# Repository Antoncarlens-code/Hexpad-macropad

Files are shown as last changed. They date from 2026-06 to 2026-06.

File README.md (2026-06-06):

# Hexpad — a hex-shaped 6-key macropad

A 6-key (3×2) macropad with a rotary encoder: 3D-printed case, custom 2-layer PCB,
and KMK firmware, driven by a **Seeed XIAO RP2040**. Keys wire **direct to GPIO**
(no matrix, no diodes), and the encoder handles volume/scroll.

<!-- HACKPAD: a full render showing ALL parts is required. Export one from the
     KiCad 3D viewer or your CAD tool and drop it at the path below. -->
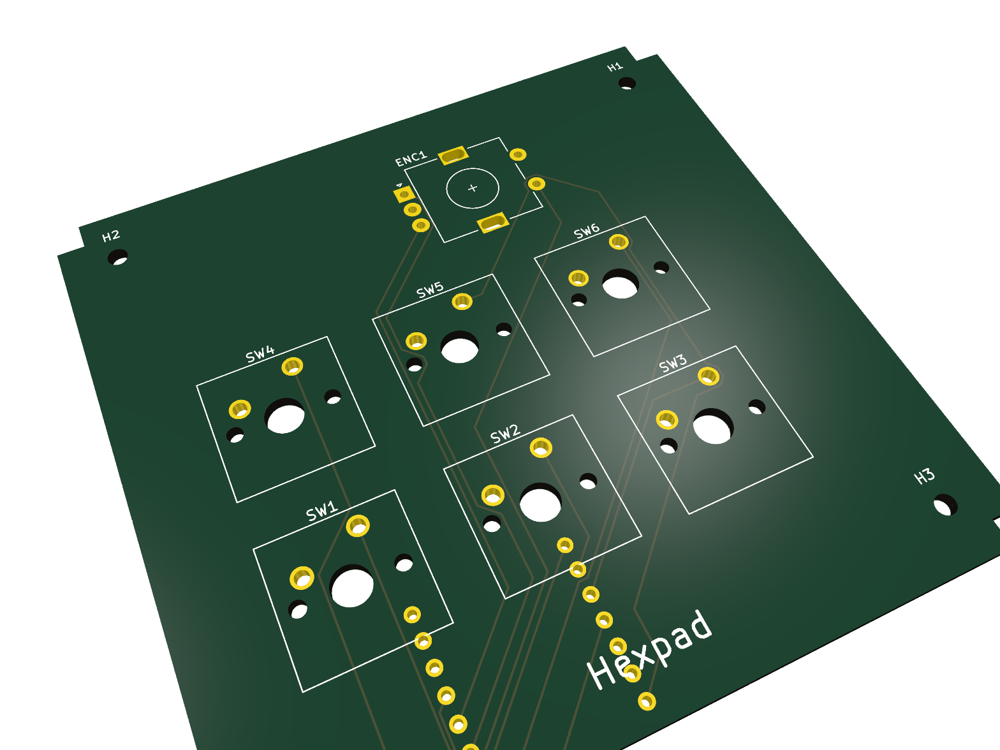
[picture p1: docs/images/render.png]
Hexpad full render


## Inspiration & challenges

I wanted a compact editing/clipboard pad with a volume knob that didn't look like
every other square macropad — so Hexpad uses a hexagonal silhouette around a
centered 3×2 key cluster with the encoder up top.

Two things were genuinely fiddly. First, the original top-plate CAD came out of an
early IDE session malformed — the plate solid was fused to a stray slab 74 mm
below it, so it "levitated" in the slicer. I had to reverse-engineer the real
dimensions from the STEP geometry and rebuild the plate as a clean parametric
build123d script. Second, rather than hand-draw the board I generated the PCB
programmatically with KiCad's `pcbnew` API from a single coordinate spec, which
guarantees the switch, encoder, and mounting-hole positions line up exactly with
the printed plate (19.05 mm pitch, mounts at ±32 × ±31 mm).

## Gallery

| Schematic | PCB | Case |
|---|-----|---|
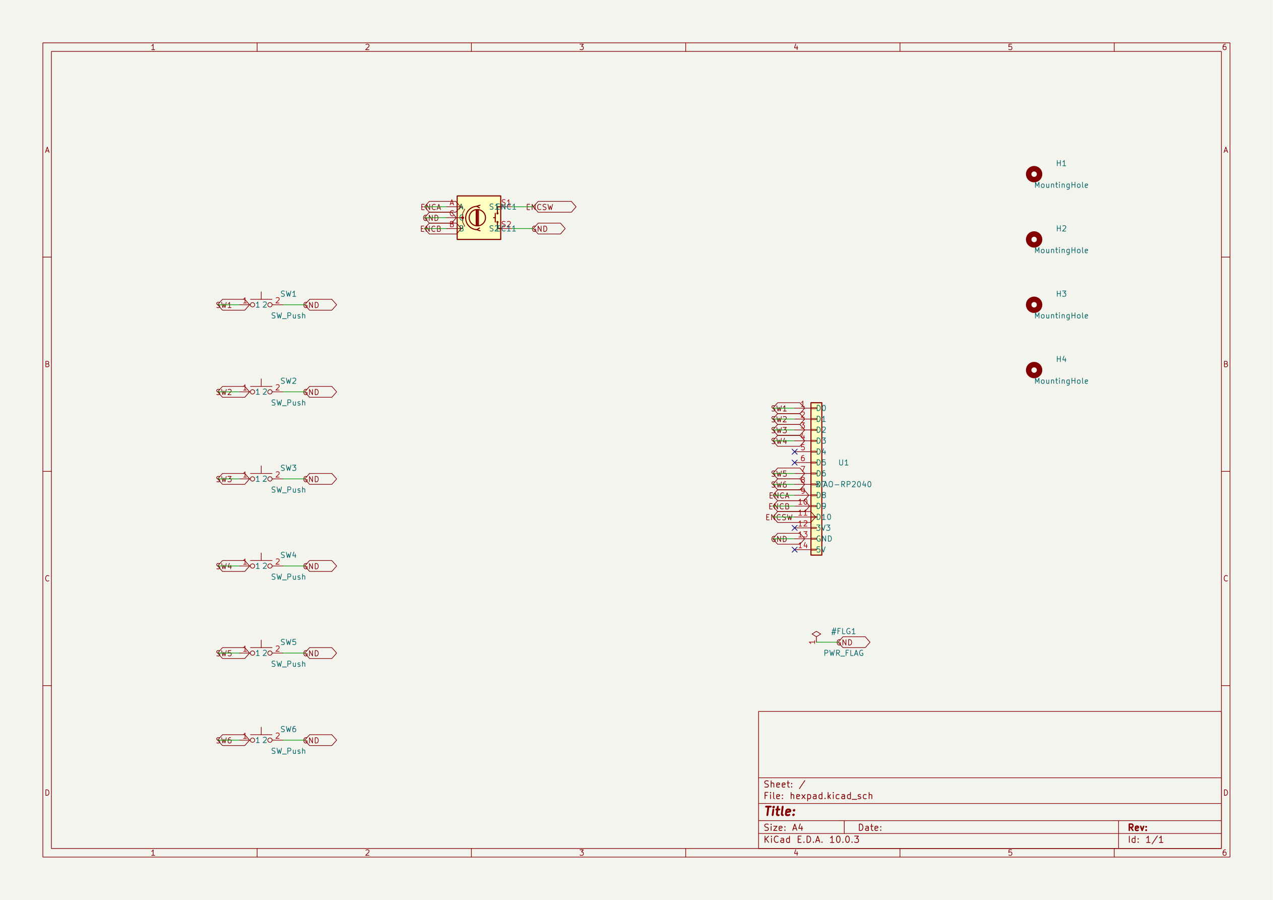
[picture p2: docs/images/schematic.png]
Schematic
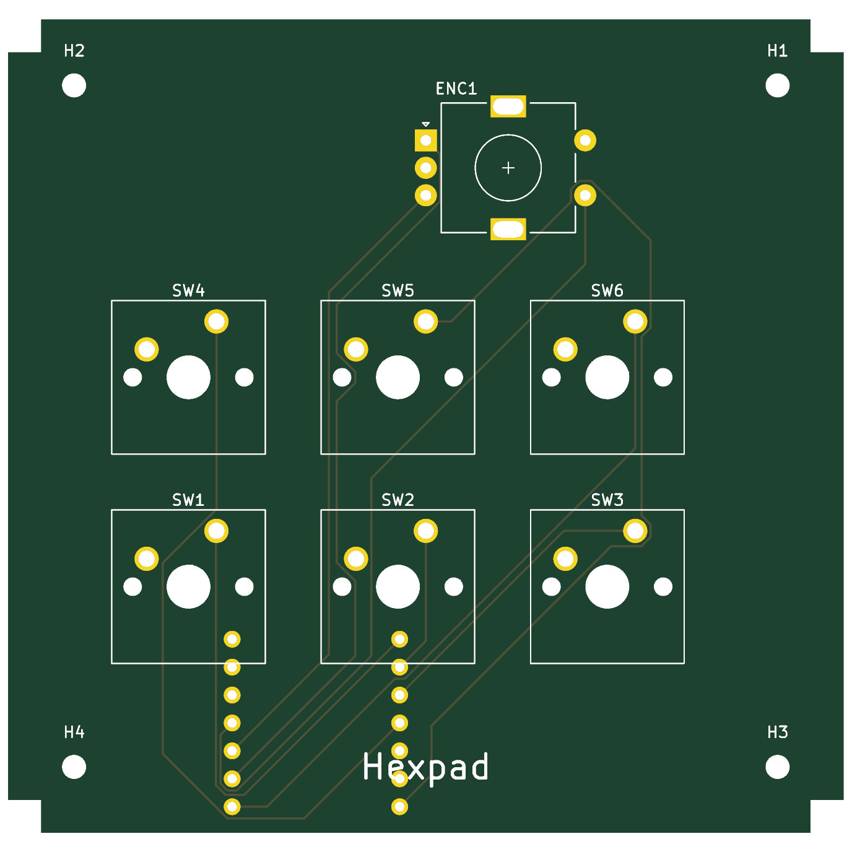
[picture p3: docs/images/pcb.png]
PCB
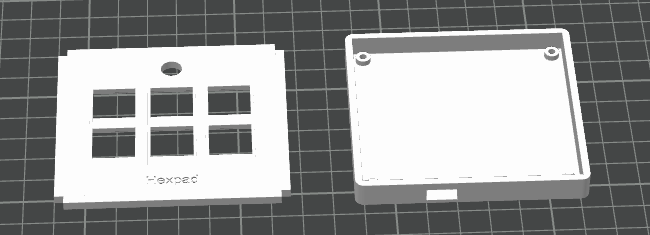
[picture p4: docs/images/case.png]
Case
|  |  |  |

<!-- HACKPAD requires a photo of each: the schematic, the PCB (KiCad render or the
     real board), and the case. Add the three images to docs/images/. -->

## Bill of materials

Full sheet: [`docs/electronics/hexpad-bom.csv`](docs/electronics/hexpad-bom.csv).

| Qty | Part | Notes |
|-----|---|---|
| 1 | Seeed XIAO RP2040 | MCU, mounted on the back; USB-C exits the front edge |
| 6 | Cherry MX (or compatible) switch | `MX_Only_1.00u`, direct-wired, one GPIO each |
| 1 | Alps EC11 rotary encoder w/ switch | A/B + push → 3 GPIO, common → GND |
| 4 | M2 screw (~6 mm) | through the case into the plate's corner posts |
| 6 / 1 | MX keycaps / encoder knob | cosmetic |
| 0 | diodes | **none** — direct wiring is valid for ≤7 keys |

## Project layout

| Folder | Contents |
|---|---|
| `cad/` | Enclosure: STEP blueprints + parametric build123d source |
| `pcb/` | KiCad 10 PCB project, schematic, + fabrication Gerbers |
| `firmware/` | KMK (CircuitPython) keymap |
| `docs/electronics/` | Schematic (SVG), BOM, PCB design notes |
| `docs/images/` | Render + schematic/PCB/case photos for this README |

## PCB

| File | Purpose |
|---|---|
| `pcb/hexpad.kicad_sch` | Schematic (XIAO + 6 switches + encoder) |
| `pcb/hexpad.kicad_pcb` | KiCad 10 board, branded, routed |
| `pcb/hexpad-gerbers.zip` | **Upload to JLCPCB** to order boards |
| `pcb/build_hexpad_pcb.py` / `build_hexpad_sch.py` | Regenerate board/schematic from the spec |

2-layer, **76 × 74 mm** (within the 100 mm limit), silkscreen-branded "Hexpad",
matching the plate's switch / encoder / mounting coordinates.

## Firmware

KMK keymap at `firmware/code.py`. Default: front row Copy/Paste/Cut, rear row
Undo/Redo/Save, encoder = volume (press = mute). See `firmware/README.md` for
flashing and remapping.

## Pin map

| Input | XIAO pin | | Input | XIAO pin |
|---|---|-|---|---|
| SW1–SW3 (front) | D0, D1, D2 | | Encoder A / B | D8 / D9 |
| SW4–SW6 (rear) | D3, D6, D7 | | Encoder push | D10 |

`D4`/`D5` (SDA/SCL) left free for a future OLED. All inputs use the RP2040's
internal pull-ups.

## Toolchain

build123d (CAD → STEP) · KiCad 10 (PCB) · Bambu Studio (slicing) · CircuitPython + KMK.

## Submission checklist (Hackpad)

- [x] DRC: 0 errors, 0 unconnected (only silk + courtyard warnings) — re-plotted after branding
- [x] "Hexpad" on the PCB silkscreen
- [x] "Hexpad" engraved on the top plate (front margin, 0.6 mm deep) — **reprint the plate to get it physically**
- [ ] 3D-printed parts need no supports / tolerances ~0.25 mm *(verify on your physical print)*
- [x] PCB < 100 × 100 mm; ≤16 switches, ≤2 encoders, ≤1 OLED, ≤16 LEDs
- [x] README photos: render + PCB + schematic + case (`docs/images/`)

## Build checklist

- [x] CAD: top plate + bottom case
- [x] PCB: schematic + routed board + Gerbers
- [x] Firmware keymap
- [x] Re-plot Gerbers after the silkscreen branding change
- [ ] Order PCB from JLCPCB · print case · solder · flash · assemble

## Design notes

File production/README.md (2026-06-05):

# Production files

Manufacturing-ready outputs for Hexpad (separate from the source/design files).

| File | What it is |
|---|---|
| `gerbers.zip` | PCB fabrication Gerbers + drill files (2-layer, 76 × 74 mm). Upload to a fab house (e.g. JLCPCB) to make the board. |
| `hexpad_top_plate.step` | Top plate — print this part. |
| `hexpad_bottom_case.step` | Bottom case — print this part. |
| `main.py` | KMK firmware. Copy onto the XIAO's CIRCUITPY drive alongside the `kmk/` library (see `../firmware/README.md`). |

Source/design files live in `../cad`, `../pcb`, and `../firmware`.

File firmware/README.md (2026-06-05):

# Firmware

KMK (CircuitPython) firmware for the hexpad macropad — 6 keys + 1 rotary encoder
on a **Seeed XIAO RP2040**. KMK is used because it needs no build toolchain:
you drag files onto the board's USB drive and edit `code.py` to remap keys.

## Files

| File | Purpose |
|---|---|
| `code.py` | The keymap + wiring. This is the firmware you edit. |

## Flash it (one-time setup)

1. **Put CircuitPython on the XIAO RP2040.**
   - Download the XIAO RP2040 build: <https://circuitpython.org/board/seeeduino_xiao_rp2040/>
   - Plug the XIAO in. Enter the bootloader: hold **BOOT**, tap **RESET**, release BOOT
     (or double-tap RESET). A drive named **RPI-RP2** appears.
   - Drag the downloaded `.uf2` onto **RPI-RP2**. It reboots as a drive named **CIRCUITPY**.
2. **Add the KMK library.**
   - Download KMK: <https://github.com/KMKfw/kmk_firmware> (green *Code → Download ZIP*).
   - Copy the **`kmk/`** folder from that zip to the root of the **CIRCUITPY** drive.
3. **Add this firmware.**
   - Copy **`firmware/code.py`** to the root of **CIRCUITPY** (replace the default `code.py`).
   - It runs immediately. Press a key / turn the knob to test.

To change keys later: just edit `code.py` on the CIRCUITPY drive and save — it
reloads automatically.

## Default keymap

```
   ( encoder: turn = volume,  press = mute )

   [ Copy ] [ Paste ] [ Cut  ]      <- front row  (SW1 SW2 SW3)
   [ Undo ] [ Redo  ] [ Save ]      <- rear row   (SW4 SW5 SW6)
```

Edit the `KC.*` entries in `code.py` to remap. Examples are in the comments
there (plain keys, Ctrl/Cmd combos, media keys).

## Pin map (matches the PCB)

Each switch: pin → GND, internal pull-up (press = LOW). No diodes.

| Key | XIAO pin | RP2040 GPIO |
|-----|---|---|
| SW1 | D0 | GPIO26 |
| SW2 | D1 | GPIO27 |
| SW3 | D2 | GPIO28 |
| SW4 | D3 | GPIO29 |
| SW5 | D6 | GPIO0 |
| SW6 | D7 | GPIO1 |
| Encoder A | D8 | GPIO2 |
| Encoder B | D9 | GPIO4 |
| Encoder push | D10 | GPIO3 |
| Encoder common / switch GND | GND | — |

`code.py` uses the `board.D#` names, so it stays correct regardless of the
underlying GPIO numbers.

## Troubleshooting (first power-on)

You can test the firmware **before** assembling the case — just flash a bare XIAO
and briefly bridge a switch pin to a GND pin with a jumper to confirm a key fires.

- **No `RPI-RP2` drive when entering the bootloader.** Use a *data* USB-C cable
  (charge-only cables won't enumerate). Re-do the bootloader: hold **BOOT**, tap
  **RESET**, release BOOT.
- **`CIRCUITPY` never appears after copying the `.uf2`.** The `.uf2` didn't take —
  re-enter the bootloader and drag it on again. Make sure you grabbed the
  *XIAO RP2040* build, not a different board.
- **Nothing happens after copying `code.py`.** There's an error. Open
  `boot_out.txt` on the CIRCUITPY drive, or connect a serial console
  (Mu editor, or `screen`/PuTTY) to see the traceback. The usual culprits:
  - **`ImportError: cannot import name 'KeysScanner'`** — the import path moved
    between KMK versions. Change the import in `code.py` to:
    `from kmk.scanners import keypad` and then use `keypad.KeysScanner(...)`.
  - **`kmk` not found** — the `kmk/` library folder isn't at the root of
    CIRCUITPY (it must be `CIRCUITPY/kmk/...`, not nested in another folder).
- **A single key does nothing** (others work) — almost always a cold solder joint
  on that switch or its pin; reflow it. To rule out the firmware, bridge that
  XIAO pin to GND by hand; if it fires, it's the joint, not the code.
- **All keys dead, encoder works (or vice-versa)** — re-check that pin list vs.
  the [pin map](#pin-map-matches-the-pcb) above.
- **Encoder turns the "wrong" way** (volume down when you expect up) — swap the
  first two entries in `encoder.map`, i.e. `(KC.VOLU, KC.VOLD, KC.MUTE)`. (Swapping
  the A/B wires does the same thing in hardware.)
- **Keys repeat / feel chattery** — add light debounce: `keyboard.debug_enabled`
  off and, if needed, raise the scanner's debounce; usually not necessary on MX.

## Prefer QMK?

QMK also runs on the RP2040 but needs a compile toolchain (`qmk` CLI, a
`info.json` declaring `direct` pins for the 6 keys + an `encoders` block, and a
`keymap.c`). KMK is recommended here for the no-build workflow; ask if you want
the QMK variant instead.

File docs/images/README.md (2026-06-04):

# README images

Drop the images the top-level README references here (Hackpad requires all four):

- `render.png` — a full render showing **all** parts (KiCad 3D viewer or CAD).
- `schematic.png` — screenshot of the KiCad schematic.
- `pcb.png` — KiCad PCB render or a photo of the real board.
- `case.png` — photo of the printed case.

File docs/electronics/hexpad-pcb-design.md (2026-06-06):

# Hexpad PCB Design Package

**Date:** 2026-06-03
**Scope:** Electrical design for the existing 6-key + encoder hexpad enclosure.
**Matches:** `cad/hexpad_top_plate.py` (constants), `cad/hexpad_assembly.step`.

This is the design half the project was missing — everything needed to build the
KiCad schematic and PCB so it drops into the printed case. All coordinates are
taken directly from the CAD source so the board lines up with the plate's switch
cutouts, encoder hole, and corner posts.

---

## 1. What this board is

A **6-key** macropad (3×2 grid) plus **one EC11 rotary encoder**, driven by a
**Seeed XIAO RP2040**. Because there are fewer than 8 keys, every switch wires
**directly to its own GPIO** — no matrix, **no diodes**. The tutorial's matrix /
`1N4148` section does not apply to this build and should be skipped.

Pin budget: 6 switches + 3 encoder = **9 GPIO**. The XIAO RP2040 exposes 11
(D0–D10), so it fits with two pins (D4/D5 = SDA/SCL) left free for a future OLED.

---

## 2. Bill of materials

See `hexpad-bom.csv` for the spreadsheet version. Summary:

| Ref | Qty | Part | Footprint |
|-----|-----|---|---|
| U1 | 1 | Seeed XIAO RP2040 | care-package XIAO (castellated) |
| SW1–SW6 | 6 | MX keyswitch 1u | `MX_Only_1.00u` (care package) |
| ENC1 | 1 | Alps EC11 encoder + switch | `RotaryEncoder_Alps_EC11E-Switch_Vertical_H20mm` |
| — | 4 | M2 screw (~6 mm) | into plate corner posts |
| — | 6 / 1 | keycaps / encoder knob | cosmetic |

Diodes: **none.** (Listed in the BOM as qty 0 for reference only.)

---

## 3. Pin map / wiring table

Switch numbering: row by row, **front row first** (front = −Y), left to right.

| Ref | Function | XIAO pin | RP2040 GPIO | Other leg |
|-----|---|---|---|---|
| SW1 | key, front-left | D0 | GPIO26 | GND |
| SW2 | key, front-center | D1 | GPIO27 | GND |
| SW3 | key, front-right | D2 | GPIO28 | GND |
| SW4 | key, rear-left | D3 | GPIO29 | GND |
| SW5 | key, rear-center | D6 | GPIO0 | GND |
| SW6 | key, rear-right | D7 | GPIO1 | GND |
| ENC1.A | encoder rotation A | D8 | GPIO2 | — |
| ENC1.B | encoder rotation B | D9 | GPIO4 | — |
| ENC1.SW | encoder push | D10 | GPIO3 | — |
| ENC1.C | encoder common | — | — | GND |
| *(reserved)* | OLED SDA | D4 | GPIO6 | future |
| *(reserved)* | OLED SCL | D5 | GPIO7 | future |

Every input uses the RP2040's **internal pull-up** (firmware: `INPUT_PULLUP`),
so a press/turn pulls the pin to GND. No external resistors. See
`hexpad-schematic.svg` for the wiring diagram.

---

## 4. PCB layout coordinates

Origin = plate center (same origin as the CAD). Units mm. **Front edge = −Y**
(the case USB-C slot is cut into the −Y wall at X −15…−5).

### Switches (center of each MX footprint) — 19.05 mm pitch

| Ref | X | Y |
|-----|---|---|
| SW1 | −19.05 | −9.525 |
| SW2 | 0.00 | −9.525 |
| SW3 | +19.05 | −9.525 |
| SW4 | −19.05 | +9.525 |
| SW5 | 0.00 | +9.525 |
| SW6 | +19.05 | +9.525 |

### Encoder

| Ref | X | Y |
|-----|---|---|
| ENC1 | 0.00 | +26.00 |

### Mounting holes (M2, must clear the plate's corner posts)

| Hole | X | Y |
|---|---|---|
| H1 | +32.00 | +31.00 |
| H2 | −32.00 | +31.00 |
| H3 | +32.00 | −31.00 |
| H4 | −32.00 | −31.00 |

X = ±32 (not ±31) to line up with the bottom-case screw bosses, which sit at
X ±32, Y ±31.

Drill Ø2.2 mm (M2 clearance), ~4 mm pad/annular keep-out.

### XIAO (U1)

Place on the **back** layer, USB-C connector pointing −Y, USB centered near
**X ≈ −10** so it lines up with the case slot. Body roughly centered at
**(−10, −27)** in the front margin below the bottom key row (which ends near
Y ≈ −16.5). Flip to B.Cu (press F in KiCad) before routing.

### Board outline (Edge.Cuts)

Match the plate footprint: **76 × 74 mm** rectangle (X ±38, Y ±37) with a
**3 × 3 mm notch at each corner**. Inset the edge **0.5 mm** all around if you
want clearance inside the case rim. Well within the 100 × 100 mm limit.

---

## 5. Build order in KiCad (condensed, tailored to this design)

1. New project → Schematic Editor. Place `MOUDLE-SEEEDUINO-XIAO`, 6× `SW_Push`,
   1× `RotaryEncoder_Switch`. **No diodes.**
2. Wire per the table in §3; place `GND` symbols on every switch's second leg and
   the encoder common.
3. Assign footprints per §2. (XIAO + `MX_Only_1.00u` come from the care package.)
4. PCB Editor → Update PCB from Schematic. Flip U1 to back.
5. Place SW1–SW6, ENC1, and the 4 mounting holes at the §4 coordinates (set grid
   to 19.05 mm for the switches).
6. Route on F.Cu; use B.Cu + a via only where traces cross.
7. Draw the §4 board outline on Edge.Cuts.
8. Cleanup Tracks & Vias → DRC (expect 0 errors) → 3D viewer check.
9. Fabrication Outputs → Gerbers + Drill files → zip as `gerbers.zip` → upload to
   JLCPCB for the preview/quote.

---

## 6. Integration checklist (board ↔ enclosure)

- [ ] Switch centers match plate cutouts (the 6 coords above = CAD `KEY_LOCS`). ✓ by design
- [ ] Encoder at (0, +26) = CAD `ENCODER_POS`. ✓ by design
- [ ] Mounting holes at (±31, ±31) = CAD `POST_LOCS`. ✓ by design
- [ ] USB-C exits −Y, aligned to case slot X −15…−5. (verify U1 placement)
- [ ] Board ≤ plate footprint 76×74, corner notches present.
- [ ] DRC clean before exporting Gerbers.

---

## 7. Firmware note (not built here)

KMK (CircuitPython) or QMK both run on the XIAO RP2040. Whichever you pick, the
keymap just maps each GPIO in §3 to a keycode and the encoder to A/B + push. The
pin map above is the single source of truth for the firmware's pin assignments.

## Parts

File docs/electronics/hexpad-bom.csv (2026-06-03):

Ref | Qty | Part | Value/Spec | Footprint | Notes
U1 | 1 | Seeed Studio XIAO RP2040 | RP2040 dev board | Care-package XIAO footprint (castellated) | Brain. Mounted on BACK so USB-C exits the -Y edge. Built-in pull-ups.
SW1-SW6 | 6 | Cherry MX (or compatible) keyswitch | MX 1.00u | MX_Only_1.00u (care package) | Direct-wired, one pin each. No diodes needed (6 keys < 8).
ENC1 | 1 | Alps EC11 rotary encoder w/ switch | EC11E | RotaryEncoder_Alps_EC11E-Switch_Vertical_H20mm | 3 signal pins (A/B/push) + common to GND.
- | 6 | MX keycaps | 1u | - | Cosmetic. Match your switch stem.
- | 1 | Encoder knob | for EC11 6mm D-shaft | - | Cosmetic.
- | 4 | M2 machine screw | M2 x ~6mm | - | Up through case bottom into the plate's 4 corner posts (O1.7 pilot).
- | 1 | USB-C cable | data-capable | - | For flashing firmware + use.
- | 0 | 1N4148 diode | - | Diode_THT:D_DO-35_SOD27_P7.62mm_Horizontal | NOT USED. Only needed for 8+ key matrix builds.

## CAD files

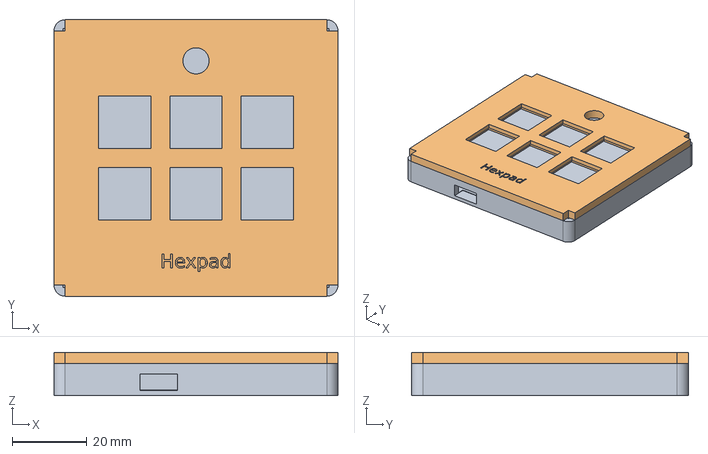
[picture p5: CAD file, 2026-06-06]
cad/hexpad_assembly.step
76.0 x 74.0 x 11.6 mm
Open_CASCADE_STEP_translator_7_8_2

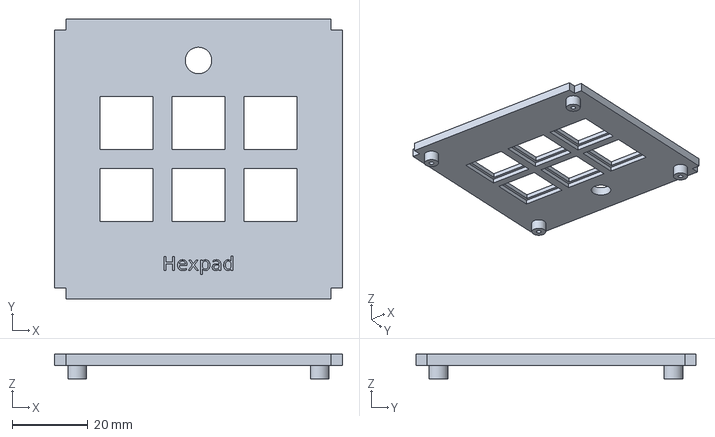
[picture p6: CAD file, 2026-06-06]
cad/hexpad_top_plate.step
76.0 x 74.0 x 6.50 mm

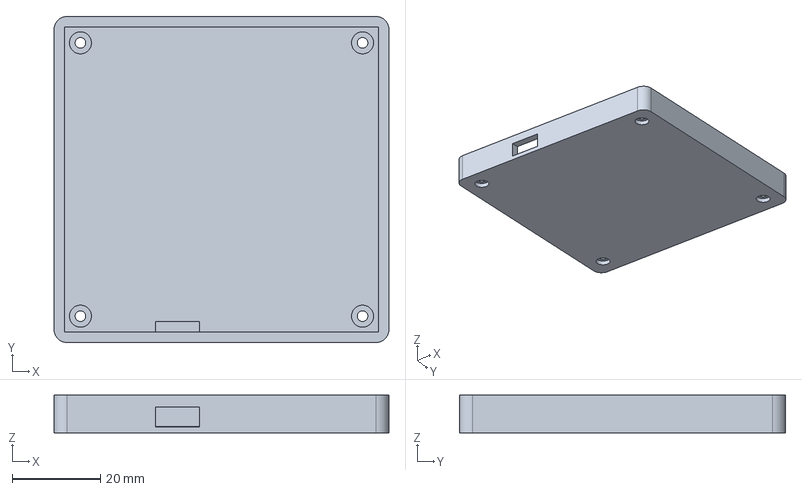
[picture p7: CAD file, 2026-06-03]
production/hexpad_bottom_case.step
76.0 x 74.0 x 8.60 mm

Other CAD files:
cad/hexpad_top_plate.3mf

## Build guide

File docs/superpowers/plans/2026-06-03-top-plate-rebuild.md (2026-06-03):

# Hexpad Top Plate Rebuild Implementation Plan

> **For agentic workers:** REQUIRED SUB-SKILL: Use superpowers:subagent-driven-development (recommended) or superpowers:executing-plans to implement this plan task-by-task. Steps use checkbox (`- [ ]`) syntax for tracking.

**Goal:** Replace the malformed `hexpad_top_plate.step` with a clean, parametric build123d-generated top plate that seats correctly on the existing bottom case.

**Architecture:** A single parametric Python script (`cad/hexpad_top_plate.py`) builds the plate from named constants and exports `hexpad_top_plate.step`, then composes it with the unchanged `hexpad_bottom_case.step` into `hexpad_assembly.step`. Geometry is verified after each stage with the existing stdlib analyzer `cad/_analyze_step.py`.

**Tech Stack:** Python + build123d (OpenCASCADE). Because only Python 3.14 is installed (no build123d/OCP wheels for 3.14 yet), the build runs inside a `uv`-managed Python 3.12 venv at `cad/.venv`. The analyzer is stdlib-only and runs on system Python 3.14.

**Spec:** `docs/superpowers/specs/2026-06-03-top-plate-rebuild-design.md`
**Branch:** `fix/top-plate-rebuild`

---

## File Structure

| File | Responsibility | Status |
|---|---|---|
| `cad/hexpad_top_plate.py` | Parametric source: constants + `build_top_plate()` + `build_assembly()` + `main()` | Create |
| `cad/hexpad_top_plate.step` | Generated clean plate | Overwrite |
| `cad/hexpad_assembly.step` | Generated plate + unchanged case | Overwrite |
| `cad/hexpad_bottom_case.step` | Clean case | **Untouched** |
| `cad/_analyze_step.py` | Per-solid bbox verifier (stdlib) | Use, then remove |
| `cad/_extract_geom.py` | Reverse-engineering helper | Remove at end |
| `.gitignore` | Ignore `cad/.venv/`, `__pycache__/` | Modify |
| `README.md` | Tick the "slice top plate" TODO context | Modify |

**Coordinate model (final, absolute Z):** plate body Z −1.5 → +1.5 (seats on case rim at −1.5); corner posts Z −5 → −1.5; stepped cutouts: 14 mm square Z 0 → +1.5, 16 mm relief Z −1.5 → 0; front edge = −Y.

---

## Task 1: Provision build123d environment

**Files:** none (environment only)

- [ ] **Step 1: Install uv (standalone, runs on 3.14)**

Run:
```powershell
python -m pip install uv
```
Expected: `Successfully installed uv-...`

- [ ] **Step 2: Install a managed Python 3.12 and create the venv**

Run:
```powershell
uv python install 3.12
uv venv cad\.venv --python 3.12
```
Expected: `Creating virtual environment at: cad\.venv`

- [ ] **Step 3: Install build123d into the venv**

Run:
```powershell
uv pip install --python cad\.venv\Scripts\python.exe build123d
```
Expected: resolves and installs `build123d`, `cadquery-ocp`, etc. (may take a few minutes).

- [ ] **Step 4: Verify the import works**

Run:
```powershell
cad\.venv\Scripts\python.exe -c "import build123d as b; print('build123d', b.__version__)"
```
Expected: prints a version (e.g. `build123d 0.9.x`). If this fails with an OCP/wheel error, try `uv python install 3.11` and recreate the venv with `--python 3.11`.

---

## Task 2: Base plate with corner notches

**Files:**
- Create: `cad/hexpad_top_plate.py`

- [ ] **Step 1: Create the script with constants + base body + main()**

Create `cad/hexpad_top_plate.py`:
```python
"""Parametric hexpad top plate (build123d).

Regenerates hexpad_top_plate.step and hexpad_assembly.step.
Spec: docs/superpowers/specs/2026-06-03-top-plate-rebuild-design.md
Run with the project venv:
    cad\\.venv\\Scripts\\python.exe cad\\hexpad_top_plate.py
"""
from pathlib import Path
from build123d import (
    BuildPart, BuildSketch, Plane, Locations, Rectangle, Circle,
    extrude, Mode, Compound, export_step, import_step,
)

CAD = Path(__file__).parent

# ---- Parameters (mm) ----
PLATE_W, PLATE_D = 76.0, 74.0
PLATE_T = 3.0
SEAT_Z = -1.5                       # plate bottom seats on case rim
TOP_Z = SEAT_Z + PLATE_T            # +1.5
CORNER_NOTCH = 3.0
LEDGE_T = 1.5
SWITCH_CUT = 14.0                   # top ledge opening
SWITCH_RELIEF = 16.0               # bottom relief opening
KEY_SPACING = 19.05
COL_X = (-KEY_SPACING, 0.0, KEY_SPACING)
ROW_Y = (-KEY_SPACING / 2, KEY_SPACING / 2)   # -9.525, +9.525
ENCODER_D = 7.0
ENCODER_POS = (0.0, 26.0)
POST_X, POST_Y = 31.0, 31.0
POST_D = 5.0
POST_PILOT_D = 1.7
POST_BOTTOM_Z = -5.0
POST_LEN = SEAT_Z - POST_BOTTOM_Z   # 3.5
PILOT_DEPTH = 5.0                   # from -5 up to 0

KEY_LOCS = [(x, y) for y in ROW_Y for x in COL_X]
POST_LOCS = [(POST_X, POST_Y), (-POST_X, POST_Y),
             (POST_X, -POST_Y), (-POST_X, -POST_Y)]
_cx = PLATE_W / 2 - CORNER_NOTCH / 2
_cy = PLATE_D / 2 - CORNER_NOTCH / 2
NOTCH_LOCS = [(_cx, _cy), (-_cx, _cy), (_cx, -_cy), (-_cx, -_cy)]

def build_top_plate():
    with BuildPart() as part:
        # base body with corner notches: SEAT_Z -> TOP_Z
        with BuildSketch(Plane.XY.offset(SEAT_Z)):
            Rectangle(PLATE_W, PLATE_D)
            with Locations(*NOTCH_LOCS):
                Rectangle(CORNER_NOTCH, CORNER_NOTCH, mode=Mode.SUBTRACT)
        extrude(amount=PLATE_T)
    return part.part

def main():
    plate = build_top_plate()
    export_step(plate, str(CAD / "hexpad_top_plate.step"))
    print("exported hexpad_top_plate.step")

if __name__ == "__main__":
    main()
```

- [ ] **Step 2: Run the script (regenerates the plate STEP)**

Run:
```powershell
cad\.venv\Scripts\python.exe cad\hexpad_top_plate.py
```
Expected: `exported hexpad_top_plate.step`

- [ ] **Step 3: Verify geometry with the analyzer**

Run:
```powershell
python cad\_analyze_step.py cad\hexpad_top_plate.step
```
Expected: `1 solid(s)`, one solid with `Z[  -1.50,   1.50]`, `X[ -38.00,  38.00]`, `Y[ -37.00,  37.00]`, `size 76.0x74.0x3.0`. **No Z = −74.5.**

- [ ] **Step 4: Commit**

```powershell
git add cad\hexpad_top_plate.py cad\hexpad_top_plate.step
git commit -m "feat(cad): base top plate body with corner notches"
```

---

## Task 3: Corner posts + pilot holes

**Files:**
- Modify: `cad/hexpad_top_plate.py` (extend `build_top_plate()`)

- [ ] **Step 1: Add posts and pilot holes to `build_top_plate()`**

Replace the `build_top_plate()` function body with:
```python
def build_top_plate():
    with BuildPart() as part:
        # base body with corner notches: SEAT_Z -> TOP_Z
        with BuildSketch(Plane.XY.offset(SEAT_Z)):
            Rectangle(PLATE_W, PLATE_D)
            with Locations(*NOTCH_LOCS):
                Rectangle(CORNER_NOTCH, CORNER_NOTCH, mode=Mode.SUBTRACT)
        extrude(amount=PLATE_T)

        # corner posts under the plate: POST_BOTTOM_Z -> SEAT_Z
        with BuildSketch(Plane.XY.offset(POST_BOTTOM_Z)):
            with Locations(*POST_LOCS):
                Circle(POST_D / 2)
        extrude(amount=POST_LEN)

        # post pilot holes (M2): POST_BOTTOM_Z -> 0
        with BuildSketch(Plane.XY.offset(POST_BOTTOM_Z)):
            with Locations(*POST_LOCS):
                Circle(POST_PILOT_D / 2)
        extrude(amount=PILOT_DEPTH, mode=Mode.SUBTRACT)
    return part.part
```

- [ ] **Step 2: Regenerate and verify**

Run:
```powershell
cad\.venv\Scripts\python.exe cad\hexpad_top_plate.py
python cad\_analyze_step.py cad\hexpad_top_plate.step
```
Expected: `1 solid(s)` (posts fuse to plate), Z extent now `Z[  -5.00,   1.50]`, size `76.0x74.0x6.5`. No Z = −74.5.

- [ ] **Step 3: Commit**

```powershell
git add cad\hexpad_top_plate.py cad\hexpad_top_plate.step
git commit -m "feat(cad): add corner mounting posts with M2 pilot holes"
```

---

## Task 4: Stepped MX switch cutouts

**Files:**
- Modify: `cad/hexpad_top_plate.py` (extend `build_top_plate()`)

- [ ] **Step 1: Add the stepped cutouts before the pilot-hole block**

Replace the `build_top_plate()` function body with:
```python
def build_top_plate():
    with BuildPart() as part:
        # base body with corner notches: SEAT_Z -> TOP_Z
        with BuildSketch(Plane.XY.offset(SEAT_Z)):
            Rectangle(PLATE_W, PLATE_D)
            with Locations(*NOTCH_LOCS):
                Rectangle(CORNER_NOTCH, CORNER_NOTCH, mode=Mode.SUBTRACT)
        extrude(amount=PLATE_T)

        # corner posts under the plate: POST_BOTTOM_Z -> SEAT_Z
        with BuildSketch(Plane.XY.offset(POST_BOTTOM_Z)):
            with Locations(*POST_LOCS):
                Circle(POST_D / 2)
        extrude(amount=POST_LEN)

        # stepped MX cutouts -- 14mm snap ledge: 0 -> TOP_Z
        with BuildSketch(Plane.XY):
            with Locations(*KEY_LOCS):
                Rectangle(SWITCH_CUT, SWITCH_CUT)
        extrude(amount=TOP_Z, mode=Mode.SUBTRACT)
        # stepped MX cutouts -- 16mm relief: 0 -> SEAT_Z
        with BuildSketch(Plane.XY):
            with Locations(*KEY_LOCS):
                Rectangle(SWITCH_RELIEF, SWITCH_RELIEF)
        extrude(amount=SEAT_Z, mode=Mode.SUBTRACT)

        # post pilot holes (M2): POST_BOTTOM_Z -> 0
        with BuildSketch(Plane.XY.offset(POST_BOTTOM_Z)):
            with Locations(*POST_LOCS):
                Circle(POST_PILOT_D / 2)
        extrude(amount=PILOT_DEPTH, mode=Mode.SUBTRACT)
    return part.part
```

- [ ] **Step 2: Regenerate and verify**

Run:
```powershell
cad\.venv\Scripts\python.exe cad\hexpad_top_plate.py
python cad\_analyze_step.py cad\hexpad_top_plate.step
```
Expected: still `1 solid(s)`, Z `[-5.00, 1.50]`. (Cutouts are internal, so the bbox is unchanged — confirms no stray geometry was introduced.)

- [ ] **Step 3: Sanity-check cutout count/positions**

Run:
```powershell
cad\.venv\Scripts\python.exe -c "from cad.hexpad_top_plate import KEY_LOCS; print(len(KEY_LOCS), KEY_LOCS)"
```
Expected: `6 [(-19.05, -9.525), (0.0, -9.525), (19.05, -9.525), (-19.05, 9.525), (0.0, 9.525), (19.05, 9.525)]`

- [ ] **Step 4: Commit**

```powershell
git add cad\hexpad_top_plate.py cad\hexpad_top_plate.step
git commit -m "feat(cad): add 6 stepped MX switch cutouts (14/16mm)"
```

---

## Task 5: Encoder hole

**Files:**
- Modify: `cad/hexpad_top_plate.py` (extend `build_top_plate()`)

- [ ] **Step 1: Add the encoder hole after the relief block, before pilot holes**

Insert this block immediately after the `# stepped MX cutouts -- 16mm relief` extrude and before the `# post pilot holes` block:
```python
        # EC11 encoder hole, through plate body: SEAT_Z -> TOP_Z
        with BuildSketch(Plane.XY.offset(SEAT_Z)):
            with Locations(ENCODER_POS):
                Circle(ENCODER_D / 2)
        extrude(amount=PLATE_T, mode=Mode.SUBTRACT)
```

- [ ] **Step 2: Regenerate and verify**

Run:
```powershell
cad\.venv\Scripts\python.exe cad\hexpad_top_plate.py
python cad\_analyze_step.py cad\hexpad_top_plate.step
```
Expected: `1 solid(s)`, Z `[-5.00, 1.50]`, unchanged bbox. No Z = −74.5.

- [ ] **Step 3: Commit**

```powershell
git add cad\hexpad_top_plate.py cad\hexpad_top_plate.step
git commit -m "feat(cad): add EC11 encoder hole at (0, 26)"
```

---

## Task 6: Assembly generation

**Files:**
- Modify: `cad/hexpad_top_plate.py` (add `build_assembly()`, extend `main()`)

- [ ] **Step 1: Add `build_assembly()` and update `main()`**

Add this function after `build_top_plate()`:
```python
def build_assembly():
    case = import_step(str(CAD / "hexpad_bottom_case.step"))
    plate = import_step(str(CAD / "hexpad_top_plate.step"))
    return Compound(label="hexpad_assembly", children=[case, plate])
```

Replace `main()` with:
```python
def main():
    plate = build_top_plate()
    export_step(plate, str(CAD / "hexpad_top_plate.step"))
    asm = build_assembly()
    export_step(asm, str(CAD / "hexpad_assembly.step"))
    print("exported hexpad_top_plate.step and hexpad_assembly.step")
```

- [ ] **Step 2: Regenerate and verify the assembly**

Run:
```powershell
cad\.venv\Scripts\python.exe cad\hexpad_top_plate.py
python cad\_analyze_step.py cad\hexpad_assembly.step
```
Expected: `2 solid(s)` — one `Z[ -10.10,  -1.50]` size `76.0x74.0x8.6` (case, unchanged) and one `Z[  -5.00,   1.50]` size `76.0x74.0x6.5` (plate). No Z = −74.5.

- [ ] **Step 3: Confirm the bottom case file is byte-identical (untouched)**

Run:
```powershell
git status --porcelain cad\hexpad_bottom_case.step
```
Expected: **no output** (file unmodified).

- [ ] **Step 4: Commit**

```powershell
git add cad\hexpad_top_plate.py cad\hexpad_assembly.step
git commit -m "feat(cad): regenerate assembly from clean plate + existing case"
```

---

## Task 7: Visual verification in Bambu Studio

**Files:** none

- [ ] **Step 1: Open the regenerated STEPs**

Run:
```powershell
& "C:\Program Files\Bambu Studio\bambu-studio.exe" cad\hexpad_top_plate.step cad\hexpad_assembly.step
```

- [ ] **Step 2: Confirm visually**

Check: plate lies flat (~3 mm), **no levitating/sinking geometry**, 6 square cutouts in a centered 3×2 grid, the encoder hole above them, 4 corner posts on the underside, and in the assembly the plate seats on the case rim. Capture a screenshot if running headless review.

---

## Task 8: Cleanup + housekeeping

**Files:**
- Modify: `.gitignore`
- Delete: `cad/_analyze_step.py`, `cad/_extract_geom.py`

- [ ] **Step 1: Ignore the venv and pycache**

Append to `.gitignore`:
```
# Python / build123d
cad/.venv/
__pycache__/
*.pyc
```

- [ ] **Step 2: Remove the temporary analysis scripts**

Run:
```powershell
Remove-Item cad\_analyze_step.py, cad\_extract_geom.py
```

- [ ] **Step 3: Commit**

```powershell
git add .gitignore cad\_analyze_step.py cad\_extract_geom.py
git commit -m "chore(cad): ignore venv, remove reverse-engineering scripts"
```

- [ ] **Step 4: Final review of the branch**

Run:
```powershell
git log --oneline master..HEAD
git diff --stat master..HEAD
```
Expected: commits for spec, base plate, posts, cutouts, encoder, assembly, cleanup; `hexpad_bottom_case.step` absent from the diff.

---

## Verification Summary (maps to spec)

- Outline 76×74 + corner notches → Task 2 (analyzer size `76.0x74.0`).
- 3 mm body, stepped 14/16 mm cutouts → Task 4.
- 6 keys, 3×2, 19.05 mm, centered → Task 4 Step 3.
- Encoder Ø7 at (0,26) → Task 5.
- 4 corner posts (±31,±31), 3.5 mm, Ø1.7 pilots → Task 3.
- Clean Z extents, no −74.5 slab → Tasks 2–6 analyzer checks.
- Assembly = clean plate + untouched case → Task 6.
- Visual confirmation → Task 7.

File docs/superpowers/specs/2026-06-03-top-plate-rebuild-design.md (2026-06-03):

# Hexpad Top Plate Rebuild — Design

**Date:** 2026-06-03
**Status:** Approved (design), pending spec review
**Branch:** `fix/top-plate-rebuild`

## Problem

The CAD blueprints in `cad/` were generated yesterday via an Antigravity IDE
session that produced only STEP exports (no source script was saved). The
top-plate blueprint is malformed:

- `hexpad_top_plate.step` solid `#49` (the plate itself) spans **Z −74.50 → 1.50
  (76 mm tall)**. Its point cloud is a correct thin plate at Z 0 → 1.5 **fused to
  a stray slab at Z = −74.5**, welded into a single watertight body. This is what
  appears to "levitate"/sink in Bambu Studio.
- `hexpad_assembly.step` inherits the broken plate solid.
- `hexpad_bottom_case.step` is **clean** (1 solid, Z −10.1 → −1.5, 8.6 mm tall)
  and stays untouched.

Because the defect is in the main solid (not a separable floating object) and the
original generator script is unrecoverable (it lived only in the Antigravity chat,
which stores history server-side), the fix is to **rebuild the top plate from a
fresh parametric script**, reverse-engineering the real design parameters from the
existing STEP geometry and the clean bottom case.

## Reverse-engineered parameters (from STEP)

- Plate footprint: **76 × 74 mm** (X ±38, Y ±37), **3 × 3 mm notch at each corner**
  (matches the bottom-case rim outline).
- Bottom-case rim top: **Z = −1.5** → the plate seats here.
- Front edge = **−Y** (bottom-case USB-C port is cut into the −Y wall, X −15…−5).
- Recovered key grid: 14 mm square MX cutouts, **19.05 mm** spacing
  (standard MX 0.75″), columns X = −19.05 / 0 / +19.05.
- Corner mounting features at **(±31, ±31)**.

## Goals

Produce a clean, printable, parametric top plate that seats correctly on the
existing bottom case, with a maintainable source file checked into the repo.

## Non-goals

- Do not modify `hexpad_bottom_case.step` (it is correct).
- Do not reproduce the original's broken asymmetry or the stray Z = −74.5 slab.
- No firmware, BOM, or wiring changes.

## Design

### Toolchain
- **build123d** (Python, OCCT-based) — produces clean STEP, readable parametric
  source. Installed via pip. (Alternatives considered: CadQuery — heavier syntax;
  OpenSCAD — exports STL not STEP, rejected.)

### Outline & fit
- 76 × 74 mm rectangle, **3 × 3 mm notch at each of the 4 corners** to match the
  case rim.
- Bottom face seats on the case rim plane at **Z = −1.5**.
- Orientation: front edge = −Y.

### Body & switch mounting
- Body thickness: **3 mm** (seats at Z −1.5, top surface at Z +1.5).
- **Stepped cutouts** (true MX snap-fit on a thick plate): each opening is two
  stacked squares —
  - **Top 1.5 mm** (Z +1.5 → 0): **14.0 mm** square — the snap ledge the switch
    body fits and the clips latch under.
  - **Bottom 1.5 mm** (Z 0 → −1.5): **16.0 mm** square relief — wider so the MX
    side clips have room to spring out and latch beneath the 14 mm ledge.
- **6 keys**, 3 × 2 grid, **19.05 mm** spacing, **centered** on the plate:
  - Column centers X = −19.05, 0, +19.05
  - Row centers Y = −9.525, +9.525

### Encoder
- **Ø7.0 mm** through hole for an EC11 rotary encoder, centered in the top margin
  at **(0, +26)**.

### Mounting
- **4 corner posts** on the underside at **(±31, ±31)**, extending from the plate
  underside (Z −1.5) down to **Z −5** (3.5 mm long).
- Each post has a **Ø1.7 mm** pilot hole for an **M2 screw inserted from the case
  bottom**, threading up into the post. Matches the recovered posts and the case
  corner bosses.

### Parameters (constants at top of script)
| Constant | Value |
|---|---|
| `PLATE_W` × `PLATE_D` | 76 × 74 mm |
| `CORNER_NOTCH` | 3 mm |
| `PLATE_T` | 3 mm |
| `LEDGE_T` | 1.5 mm |
| `SWITCH_CUT` | 14.0 mm (top ledge) |
| `SWITCH_RELIEF` | 16.0 mm (bottom relief) |
| `KEY_SPACING` | 19.05 mm |
| `COLS` × `ROWS` | 3 × 2 |
| `SEAT_Z` | −1.5 mm |
| `ENCODER_D` | 7.0 mm |
| `ENCODER_POS` | (0, 26) |
| `POST_POS` | (±31, ±31) |
| `POST_LEN` | 3.5 mm |
| `POST_PILOT_D` | 1.7 mm |

## Deliverables

- `cad/hexpad_top_plate.py` — parametric build123d source (constants at top).
- Regenerated `cad/hexpad_top_plate.step` — clean, ~3 mm tall plate (Z −5 → 1.5
  including posts), no Z = −74.5 slab.
- Regenerated `cad/hexpad_assembly.step` — new plate + unchanged bottom case,
  correctly positioned.
- `cad/hexpad_bottom_case.step` — **unchanged**.

## Verification

1. **Geometry sanity** (`_analyze_step.py`): top-plate solids have sane Z extents
   (no −74.5 slab); plate body ~3 mm; assembly has plate + case at correct Z.
2. **Visual**: open regenerated STEPs in Bambu Studio — plate sits flat, no
   levitating parts, encoder + 6 cutouts present, seats on case.
3. **Fit check**: plate outline and corner posts align with the bottom case in the
   assembly view.

## Cleanup

Remove the temporary analysis scripts `cad/_analyze_step.py` and
`cad/_extract_geom.py` after verification passes (they served only the
reverse-engineering step).

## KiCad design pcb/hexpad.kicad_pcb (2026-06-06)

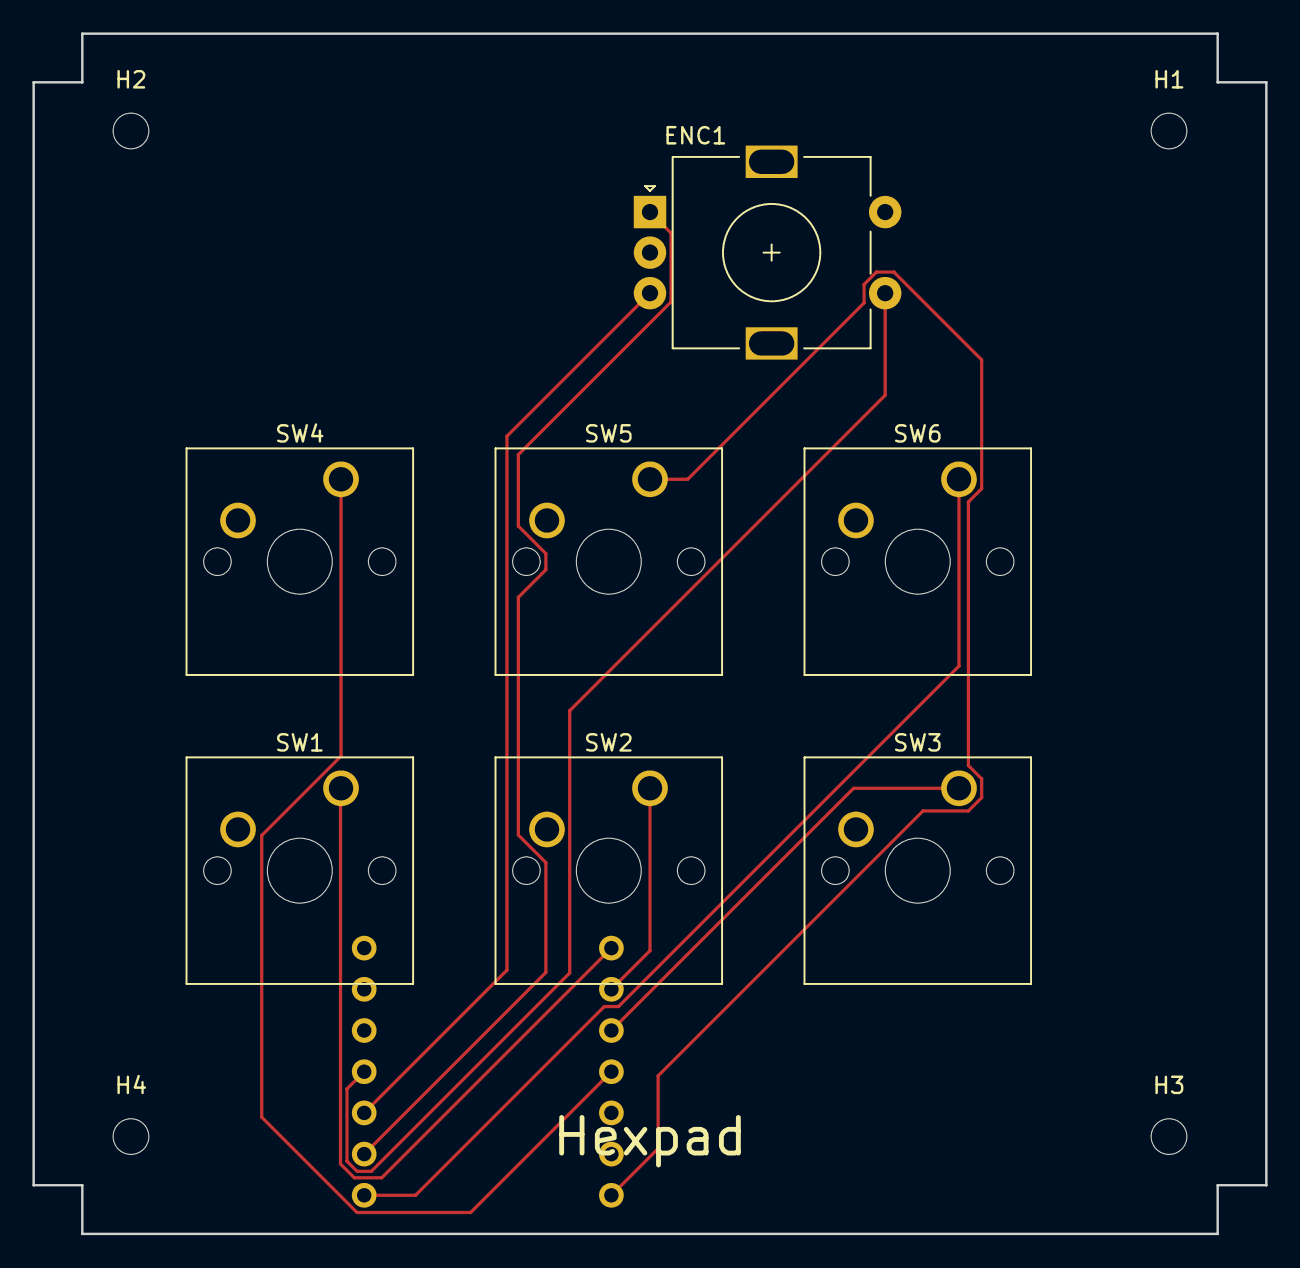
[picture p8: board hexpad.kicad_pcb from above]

Board: 2 copper layers, 76.0 x 74.0 mm, 12 parts (1 on the bottom side), 10 nets.

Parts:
ENC1: EC11; RotaryEncoder_Alps_EC11E-Switch_Vertical_H20mm
H1, H2, H3, H4: M2; MountingHole_2.2mm_M2
SW1, SW2, SW3, SW4, SW5, SW6: SW_MX; SW_Cherry_MX_1.00u_PCB
U1: XIAO-RP2040

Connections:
ENCA: ENC1.A, U1.9
ENCB: ENC1.B, U1.10
ENCSW: ENC1.S1, U1.11
GND: ENC1.C, ENC1.MP, ENC1.S2, SW1.2, SW2.2, SW3.2, SW4.2, SW5.2, SW6.2, U1.13
SW1: SW1.1, U1.1
SW2: SW2.1, U1.2
SW3: SW3.1, U1.3
SW4: SW4.1, U1.4
SW5: SW5.1, U1.7
SW6: SW6.1, U1.8

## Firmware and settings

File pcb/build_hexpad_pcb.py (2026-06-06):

"""Generate the hexpad PCB (KiCad 10 / pcbnew) from the electronics design spec.

Spec: docs/electronics/hexpad-pcb-design.md
6-key (3x2) macropad + EC11 encoder, driven by a Seeed XIAO RP2040.
No matrix / no diodes -- each switch wires direct to a GPIO, other leg to GND.

Run with KiCad's bundled Python:
    & "C:/Program Files/KiCad/10.0/bin/python.exe" pcb/build_hexpad_pcb.py

Coordinates follow the CAD/spec frame (origin = board center, +Y = rear).
KiCad uses Y-down, so every Y is negated on the way in (yk = -y). The layout is
Y-symmetric except the encoder (+26) and XIAO (rear/front), so this only flips
front/back consistently for the whole board.
"""
import os
import pcbnew
from pcbnew import VECTOR2I, FromMM

KICAD = r"C:/Program Files/KiCad/10.0/share/kicad/footprints"
OUT = os.path.join(os.path.dirname(os.path.abspath(__file__)), "hexpad.kicad_pcb")

TRACK_W = FromMM(0.40)
CLEAR = FromMM(0.20)


def xy(x, y):
    """Spec mm -> KiCad VECTOR2I (Y negated)."""
    return VECTOR2I(FromMM(x), FromMM(-y))


# ---------------------------------------------------------------- nets
def main():
    board = pcbnew.BOARD()

    # design rules: 0.2mm clearance, 0.4mm default track
    ds = board.GetDesignSettings()
    ds.m_TrackMinWidth = FromMM(0.20)
    ds.m_MinClearance = CLEAR

    nets = {}
    def net(name):
        if name not in nets:
            n = pcbnew.NETINFO_ITEM(board, name)
            board.Add(n)
            nets[name] = n
        return nets[name]

    GND = net("GND")
    for nm in ("SW1", "SW2", "SW3", "SW4", "SW5", "SW6", "ENCA", "ENCB", "ENCSW"):
        net(nm)

    # ---------------------------------------------------------- footprints
    def load(lib, name):
        fp = pcbnew.FootprintLoad(os.path.join(KICAD, lib), name)
        if fp is None:
            raise RuntimeError(f"footprint not found: {lib}/{name}")
        board.Add(fp)
        return fp

    def setnet(fp, padnum, netobj):
        for p in fp.Pads():
            if p.GetNumber() == str(padnum):
                p.SetNet(netobj)
                return
        raise RuntimeError(f"pad {padnum} not on {fp.GetReference()}")

    def place(fp, ref, val, x, y, rot=0, back=False):
        fp.SetReference(ref)
        fp.SetValue(val)
        fp.SetPosition(xy(x, y))
        if rot:
            fp.SetOrientationDegrees(rot)
        if back:
            fp.Flip(fp.GetPosition(), False)

    # switches: SW pad "1" = signal (to GPIO), pad "2" = GND
    sw_pos = {
        "SW1": (-19.05, -9.525, "SW1"),
        "SW2": (0.00, -9.525, "SW2"),
        "SW3": (19.05, -9.525, "SW3"),
        "SW4": (-19.05, 9.525, "SW4"),
        "SW5": (0.00, 9.525, "SW5"),
        "SW6": (19.05, 9.525, "SW6"),
    }
    for ref, (x, y, signet) in sw_pos.items():
        fp = load("Button_Switch_Keyboard.pretty", "SW_Cherry_MX_1.00u_PCB")
        place(fp, ref, "SW_MX", x, y)
        setnet(fp, 1, net(signet))
        setnet(fp, 2, GND)

    # encoder: A,B -> ENCA,ENCB ; S1 -> ENCSW ; C,S2,MP -> GND
    enc = load("Rotary_Encoder.pretty", "RotaryEncoder_Alps_EC11E-Switch_Vertical_H20mm")
    place(enc, "ENC1", "EC11", 0.0, 26.0)
    setnet(enc, "A", net("ENCA"))
    setnet(enc, "B", net("ENCB"))
    setnet(enc, "S1", net("ENCSW"))
    for pn in ("C", "S2", "MP"):
        setnet(enc, pn, GND)

    # mounting holes (mechanical, no net) -- X=32 to match the case screw bosses
    for ref, (x, y) in {"H1": (32, 31), "H2": (-32, 31),
                        "H3": (32, -31), "H4": (-32, -31)}.items():
        h = load("MountingHole.pretty", "MountingHole_2.2mm_M2")
        place(h, ref, "M2", x, y)

    # ---------------------------------------------------------- XIAO (built in code)
    xiao = pcbnew.FOOTPRINT(board)
    xiao.SetReference("U1")
    xiao.SetValue("XIAO-RP2040")
    # 14 THT pads, 2.54 pitch, rows +/-7.62 ; pin1=D0..pin11=D10, 12=3V3,13=GND,14=5V
    pad_x_top = [7.62, 5.08, 2.54, 0.0, -2.54, -5.08, -7.62]      # pads 1..7
    pad_x_bot = [-7.62, -5.08, -2.54, 0.0, 2.54, 5.08, 7.62]      # pads 8..14
    layout = [(i + 1, pad_x_top[i], -7.62) for i in range(7)] + \
             [(i + 8, pad_x_bot[i], 7.62) for i in range(7)]
    for num, px, py in layout:
        pad = pcbnew.PAD(xiao)
        pad.SetNumber(str(num))
        pad.SetShape(pcbnew.PAD_SHAPE_CIRCLE)
        pad.SetAttribute(pcbnew.PAD_ATTRIB_PTH)
        pad.SetSize(VECTOR2I(FromMM(1.524), FromMM(1.524)))
        pad.SetDrillSize(VECTOR2I(FromMM(0.889), FromMM(0.889)))
        pad.SetPosition(VECTOR2I(FromMM(px), FromMM(py)))
        pad.SetLayerSet(pad.PTHMask())
        xiao.Add(pad)
    board.Add(xiao)
    place(xiao, "U1", "XIAO-RP2040", -10.0, -27.0, rot=90, back=True)
    # net map per spec section 3
    xiao_nets = {1: "SW1", 2: "SW2", 3: "SW3", 4: "SW4", 7: "SW5", 8: "SW6",
                 9: "ENCA", 10: "ENCB", 11: "ENCSW", 13: "GND"}
    for pn, netname in xiao_nets.items():
        setnet(xiao, pn, GND if netname == "GND" else net(netname))

    # ---------------------------------------------------------- board outline
    # 76x74 rectangle (X +/-38, Y +/-37) with 3x3 corner notches (12 verts)
    outline = [
        (-35, 37), (35, 37), (35, 34), (38, 34), (38, -34), (35, -34),
        (35, -37), (-35, -37), (-35, -34), (-38, -34), (-38, 34), (-35, 34),
    ]
    for i in range(len(outline)):
        a = outline[i]
        b = outline[(i + 1) % len(outline)]
        seg = pcbnew.PCB_SHAPE(board)
        seg.SetShape(pcbnew.SHAPE_T_SEGMENT)
        seg.SetStart(xy(*a))
        seg.SetEnd(xy(*b))
        seg.SetLayer(pcbnew.Edge_Cuts)
        seg.SetWidth(FromMM(0.15))
        board.Add(seg)

    # ---------------------------------------------------------- GND pour (B.Cu)
    # Bottom ground plane; signals route on F.Cu. Outline only -- the fill is
    # done in route_and_export.py (headless ZONE_FILLER is unstable mid-build).
    zone = pcbnew.ZONE(board)
    zone.SetLayer(pcbnew.B_Cu)
    zone.SetNet(GND)
    zone.SetLocalClearance(CLEAR)
    sps = zone.Outline()
    sps.NewOutline()
    for (x, y) in outline:
        sps.Append(FromMM(x), FromMM(-y))
    board.Add(zone)

    # ---------------------------------------------------------- branding (silk)
    # Hackpad rule: every part must carry the hackpad's name. Front silkscreen,
    # centered along the front edge between the two front mounting holes.
    brand = pcbnew.PCB_TEXT(board)
    brand.SetText("Hexpad")
    brand.SetLayer(pcbnew.F_SilkS)
    brand.SetPosition(xy(0.0, -31.0))
    brand.SetTextSize(VECTOR2I(FromMM(2.2), FromMM(2.2)))
    brand.SetTextThickness(FromMM(0.3))
    board.Add(brand)

    board.BuildConnectivity()
    pcbnew.SaveBoard(OUT, board)
    print(f"saved {OUT}")
    print(f"footprints: {len(board.GetFootprints())}  nets: {board.GetNetCount()}  "
          f"zones: {len(board.Zones())}")


if __name__ == "__main__":
    main()

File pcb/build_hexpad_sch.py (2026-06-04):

"""Generate hexpad.kicad_sch (schematic) matching the PCB's nets, via kiutils.

12 components: U1 (XIAO RP2040), SW1-6 (SW_Push), ENC1 (RotaryEncoder_Switch),
H1-4 (MountingHole), plus a PWR_FLAG on GND. Pins are connected with global
labels named after the board nets (SW1..SW6, ENCA, ENCB, ENCSW, GND); unused
XIAO pins get no-connects. Verify with: kicad-cli sch erc.

Run: python pcb/build_hexpad_sch.py
"""
import copy, os, uuid as uuidlib
from kiutils.schematic import Schematic
from kiutils.symbol import SymbolLib
from kiutils.items.schitems import SchematicSymbol, GlobalLabel, NoConnect, Connection
from kiutils.items.common import Position, Property, Effects, Font

SYM = r"C:/Program Files/KiCad/10.0/share/kicad/symbols"
OUT = os.path.join(os.path.dirname(os.path.abspath(__file__)), "hexpad.kicad_sch")
GRID = 1.27  # KiCad schematic connection grid (50 mil)

def U():
    return str(uuidlib.uuid4())

def g(v):  # snap to connection grid
    return round(v / GRID) * GRID

def load(libfile, name):
    lib = SymbolLib.from_file(os.path.join(SYM, libfile))
    for s in lib.symbols:
        if s.entryName == name:
            return copy.deepcopy(s)
    raise SystemExit(f"symbol not found: {name}")

# ---- XIAO symbol from a 14-pin connector, pins renamed ----
XIAO_PINS = {1:"D0",2:"D1",3:"D2",4:"D3",5:"D4",6:"D5",7:"D6",
             8:"D7",9:"D8",10:"D9",11:"D10",12:"3V3",13:"GND",14:"5V"}
xiao = load("Connector_Generic.kicad_sym", "Conn_01x14")
xiao.libId = "hexpad:XIAO-RP2040"
xiao.entryName = "XIAO-RP2040"
for u in xiao.units:
    for p in u.pins:
        p.name = XIAO_PINS[int(p.number)]
for pr in xiao.properties:
    if pr.key == "Value":
        pr.value = "XIAO-RP2040"
xiao_local = {int(p.number): (p.position.X, p.position.Y)
              for u in xiao.units for p in u.pins}

# standard symbols keep their real library nicknames (no "lib not configured" warning)
sw = load("Switch.kicad_sym", "SW_Push");                 sw.libId = "Switch:SW_Push"
enc = load("Device.kicad_sym", "RotaryEncoder_Switch");   enc.libId = "Device:RotaryEncoder_Switch"
mh = load("Mechanical.kicad_sym", "MountingHole");        mh.libId = "Mechanical:MountingHole"
pf = load("power.kicad_sym", "PWR_FLAG");                 pf.libId = "power:PWR_FLAG"

sch = Schematic.create_new()
sch.libSymbols = [xiao, sw, enc, mh, pf]

def eff():
    return Effects(font=Font(height=1.27, width=1.27))

def add_symbol(nick, entry, ref, value, x, y, angle=0):
    x, y = g(x), g(y)
    s = SchematicSymbol(libraryNickname=nick, entryName=entry,
                        position=Position(x, y, angle), unit=1, uuid=U())
    s.properties = [
        Property(key="Reference", value=ref, id=0, position=Position(x + 6.35, y - 2.54, 0), effects=eff()),
        Property(key="Value", value=value, id=1, position=Position(x + 6.35, y + 2.54, 0), effects=eff()),
    ]
    sch.schematicSymbols.append(s)
    return x, y

def label(net, x, y, angle=0):
    sch.globalLabels.append(
        GlobalLabel(text=net, shape="bidirectional", position=Position(x, y, angle), effects=eff()))

def noconn(x, y):
    sch.noConnects.append(NoConnect(position=Position(x, y)))

STUB = 5.08  # 200 mil wire stub so each label sits clear of its symbol

def wire(x1, y1, x2, y2):
    c = Connection(type="wire", points=[Position(g(x1), g(y1)), Position(g(x2), g(y2))])
    c.uuid = U()
    sch.graphicalItems.append(c)

def stub_label(net, ax, ay, angle):
    """Draw a short stub off the pin and put the global label at its far end."""
    dx = {0: STUB, 180: -STUB}.get(angle, 0)
    dy = {90: -STUB, 270: STUB}.get(angle, 0)
    ex, ey = ax + dx, ay + dy
    if dx or dy:
        wire(ax, ay, ex, ey)
    label(net, ex, ey, angle)

def apin(sx, sy, local):  # angle 0, no mirror: abs = (x+px, y-py)
    return (sx + local[0], sy - local[1])

# ---- XIAO (right) ----
ux, uy = add_symbol("hexpad", "XIAO-RP2040", "U1", "XIAO-RP2040", 190.5, 110.49)
xiao_net = {1:"SW1", 2:"SW2", 3:"SW3", 4:"SW4", 7:"SW5", 8:"SW6",
            9:"ENCA", 10:"ENCB", 11:"ENCSW", 13:"GND"}
xiao_nc = [5, 6, 12, 14]
for pn, loc in xiao_local.items():
    ax, ay = apin(ux, uy, loc)
    if pn in xiao_net:
        stub_label(xiao_net[pn], ax, ay, 180)
    elif pn in xiao_nc:
        noconn(ax, ay)

# ---- switches (left column): pin1 = signal, pin2 = GND ----
for i, net in enumerate(["SW1", "SW2", "SW3", "SW4", "SW5", "SW6"]):
    sx, sy = add_symbol("Switch", "SW_Push", f"SW{i+1}", "SW_Push", 60.96, 71.12 + i * 20.32)
    p1 = apin(sx, sy, (-5.08, 0)); stub_label(net, p1[0], p1[1], 180)
    p2 = apin(sx, sy, (5.08, 0));  stub_label("GND", p2[0], p2[1], 0)

# ---- encoder (top-left) ----
ex, ey = add_symbol("Device", "RotaryEncoder_Switch", "ENC1", "EC11", 111.76, 50.8)
for loc, net, ang in [((-7.62, 2.54), "ENCA", 180), ((-7.62, -2.54), "ENCB", 180),
                      ((-7.62, 0.0), "GND", 180), ((7.62, 2.54), "ENCSW", 0),
                      ((7.62, -2.54), "GND", 0)]:
    ax, ay = apin(ex, ey, loc); stub_label(net, ax, ay, ang)

# ---- PWR_FLAG on GND ----
px, py = add_symbol("power", "PWR_FLAG", "#FLG1", "PWR_FLAG", 190.5, 149.86)
fx, fy = apin(px, py, (0.0, 0.0)); stub_label("GND", fx, fy, 0)

# ---- mounting holes (no pins) ----
for i, (hx, hy) in enumerate([(241.3, 40.64), (241.3, 55.88), (241.3, 71.12), (241.3, 86.36)]):
    add_symbol("Mechanical", "MountingHole", f"H{i+1}", "MountingHole", hx, hy)

sch.to_file(OUT)

# project symbol library + table so the custom XIAO lib is "configured"
# (removes the last ERC "library not in configuration" warning)
PROJ = os.path.dirname(OUT)
xlib = SymbolLib()
xlib.filePath = os.path.join(PROJ, "hexpad.kicad_sym")
xiao_libcopy = copy.deepcopy(xiao)
xiao_libcopy.libId = "XIAO-RP2040"
xlib.symbols = [xiao_libcopy]
xlib.to_file(xlib.filePath)
with open(os.path.join(PROJ, "sym-lib-table"), "w") as f:
    f.write('(sym_lib_table\n  (version 7)\n'
            '  (lib (name "hexpad")(type "KiCad")'
            '(uri "${KIPRJMOD}/hexpad.kicad_sym")(options "")(descr "hexpad project symbols"))\n)\n')

print(f"wrote {OUT}: {len(sch.schematicSymbols)} symbols, "
      f"{len(sch.globalLabels)} labels, {len(sch.noConnects)} no-connects")

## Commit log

2026-06-03 Initial commit: hexpad macropad CAD blueprints + project structure
    [hexpad_assembly.step, hexpad_bottom_case.step, hexpad_top_plate.step]
2026-06-03 Add design spec for top-plate rebuild
    Reverse-engineered the malformed hexpad_top_plate.step (main solid stretched
    to 76mm / fused to a stray Z=-74.5 slab) into a clean parametric design:
    76x74 plate, stepped 14mm MX cutouts (3x2, 19.05mm), EC11 encoder hole, and
    4 corner posts matching the existing bottom case. Bottom case stays untouched.
2026-06-03 Add implementation plan for top-plate rebuild
    8 tasks: provision build123d via uv/Python 3.12 venv, build the plate
    incrementally (base+notches, posts, stepped MX cutouts, encoder), regenerate
    the assembly from the untouched bottom case, verify in Bambu Studio, clean up.
2026-06-03 feat(cad): base top plate body with corner notches
    [hexpad_top_plate.step]
2026-06-03 feat(cad): add corner mounting posts with M2 pilot holes
    [hexpad_top_plate.step]
2026-06-03 feat(cad): add 6 stepped MX switch cutouts (14/16mm)
    [hexpad_top_plate.step]
2026-06-03 feat(cad): add EC11 encoder hole at (0, 26)
    [hexpad_top_plate.step]
2026-06-03 feat(cad): regenerate assembly from clean plate + existing case
    [hexpad_assembly.step, hexpad_top_plate.step]
2026-06-03 fix(cad): use forward slashes in docstring to silence SyntaxWarning
    [hexpad_assembly.step, hexpad_top_plate.step]
2026-06-03 chore(cad): ignore venv, remove reverse-engineering scripts
2026-06-03 Add hexpad PCB: placed board + GND pour (KiCad 10 / pcbnew)
    - pcb/build_hexpad_pcb.py generates hexpad.kicad_pcb from the design spec:
    6 MX switches (3x2) + EC11 encoder + XIAO RP2040, all at the CAD-matched
    coordinates, notched 76x74 outline, 4 M2 mounting holes, B.Cu GND pour.
    - XIAO footprint built in code from Seeed's official land pattern (14 THT pads,
    2.54mm pitch, 15.24mm rows). MX/EC11/mounting-hole from KiCad's bundled libs.
    - Nets assigned per the pin map (no diodes; switch->GPIO, other leg->GND).
    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
    [hexpad-bom.csv, hexpad.kicad_pcb]
2026-06-03 Prep hexpad PCB for interactive routing (fill GND pour, 0.4mm tracks)
    [hexpad.kicad_pcb]
2026-06-03 Fix PCB: move XIAO down 3mm to clear front switch holes
    Resolves the hole-overlap (U1 pin1 vs SW2 center post) and mask-bridge DRC
    errors. Remaining items are cosmetic (courtyard/silk) and don't affect Gerbers.
    Board is placement-correct; signal routing to be redone at the new position.
    [hexpad.kicad_pcb]
2026-06-03 Route hexpad PCB + export JLCPCB Gerbers
    All 9 signal nets routed (interactive), DRC clean: 0 unconnected, 0 copper/
    clearance/short/crossing violations. Remaining 4 DRC items are cosmetic
    (courtyard/silk-over-copper) and do not affect fabrication.
    Exported standard 2-layer Gerber set + Excellon drill (PTH/NPTH), zipped to
    pcb/hexpad-gerbers.zip ready for JLCPCB upload.
    [hexpad-B_Cu.gbr, hexpad-B_Mask.gbr, hexpad-B_Silkscreen.gbr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]
2026-06-03 chore(pcb): track gerber zip only; ignore KiCad lock/history files
    [hexpad-B_Cu.gbr, hexpad-B_Mask.gbr, hexpad-B_Silkscreen.gbr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]
2026-06-03 Add KMK firmware keymap for the macropad
    CircuitPython/KMK code.py for the XIAO RP2040: 6 direct-wired keys (internal
    pull-ups, no diodes) + EC11 encoder, mapped per the PCB pin map. Default keymap:
    Copy/Paste/Cut/Undo/Redo/Save + volume knob (press = mute). README covers
    flashing CircuitPython, installing KMK, and remapping. QMK noted as an option.
2026-06-03 docs: update README for PCB + firmware (full project state)
2026-06-03 Add schematic matching the PCB (ERC clean: 0 errors, 0 warnings)
    Generated hexpad.kicad_sch via kiutils: 12 components (U1 XIAO RP2040, SW1-6,
    ENC1, H1-4) wired with global labels to the same nets as the board (switch ->
    GPIO, other leg -> GND; encoder A/B/SW; PWR_FLAG on GND; no-connects on unused
    XIAO pins). Custom XIAO symbol + project sym-lib-table so the library resolves.
    Verified with kicad-cli sch erc.
    [hexpad.kicad_sch]
2026-06-04 PCB: silk-brand "Hexpad", re-plot Gerbers, add render/pcb/schematic images
    - build_hexpad_pcb.py adds "Hexpad" to F.SilkS; board + gerbers re-plotted so
    the silkscreen branding is included in hexpad-gerbers.zip.
    - DRC: 0 errors, 0 unconnected (pth_inside_courtyard reclassified to warning --
    the XIAO is intentionally back-mounted under the front switches, a benign
    cross-layer courtyard overlap; remaining warnings are silk-over-copper).
    - Schematic ERC verified clean (0 violations).
    - docs/images/: render.png, pcb.png, schematic.png (case photo still TODO).
    [hexpad.kicad_pcb]
2026-06-04 docs: honest submission checklist (PCB branded, case branding still TODO)
2026-06-04 cad: engrave "Hexpad" on the top plate; add case image
    Adds recessed "Hexpad" text (front margin, 0.6 mm deep) to the parametric top
    plate and regenerates the STEPs, so the case design carries the hackpad name.
    Adds docs/images/case.png and marks the case-branding / photos checklist items.
    [hexpad_assembly.step, hexpad_top_plate.step]
2026-06-04 Add schematic, brand PCB + plate, Hackpad submission prep
    Schematic + custom XIAO symbol; silkscreen + plate branding; KMK keymap; BOM/docs; gitignore cleanup.
2026-06-04 schematic: add wire stubs so labels don't overlap symbols
    [hexpad.kicad_sch]
2026-06-04 docs: regenerate schematic.png from stub-routed schematic (readable labels)
2026-06-04 chore: ignore KiCad .rpt report artifacts
2026-06-05 docs: replace case.png with a cleaner shot of both printed parts
    Shows the branded top plate (Hexpad engraving) + bottom case with USB-C cutout.
2026-06-05 firmware: add first-power-on troubleshooting guide
2026-06-05 Add production folder (gerbers, case STEPs, firmware) + web demo
    [hexpad_bottom_case.step, hexpad_top_plate.step]
2026-06-06 fix: move mounting holes/posts to X=+/-32 to align with case (routing preserved)
    The PCB holes and top-plate posts sat at X=+/-31, but the bottom-case screw
    bosses are at X=+/-32, Y=+/-31 (verified from the STEP via circular-edge centers)
    -- so the case didn't line up. Moved PCB holes + CAD posts to +/-32.
    The board was regenerated by build_hexpad_pcb.py which wiped the interactive
    routing; recovered the 58 routed segments from the prior commit and moved only
    the 4 (net-less) mounting holes, so routing + GND pour + silk branding are intact.
    DRC: 0 errors, 0 unconnected (courtyard severity re-set to warning). Gerbers
    re-plotted to pcb/ and production/.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
    [hexpad.kicad_pcb, hexpad_assembly.step, hexpad_top_plate.step]
2026-06-06 fix: align mounting holes to bottom case (X 31 to 32); regenerate PCB + gerbers
    [hexpad_top_plate.3mf]
2026-06-06 docs: regenerate PCB render/pcb images from the +/-32 board
2026-06-06 chore: track +/-32 sliced 3mf; ignore submission staging
    The top_plate.3mf is re-sliced from the +/-32 plate (verified posts at +/-32).
    [hexpad_top_plate.3mf]
